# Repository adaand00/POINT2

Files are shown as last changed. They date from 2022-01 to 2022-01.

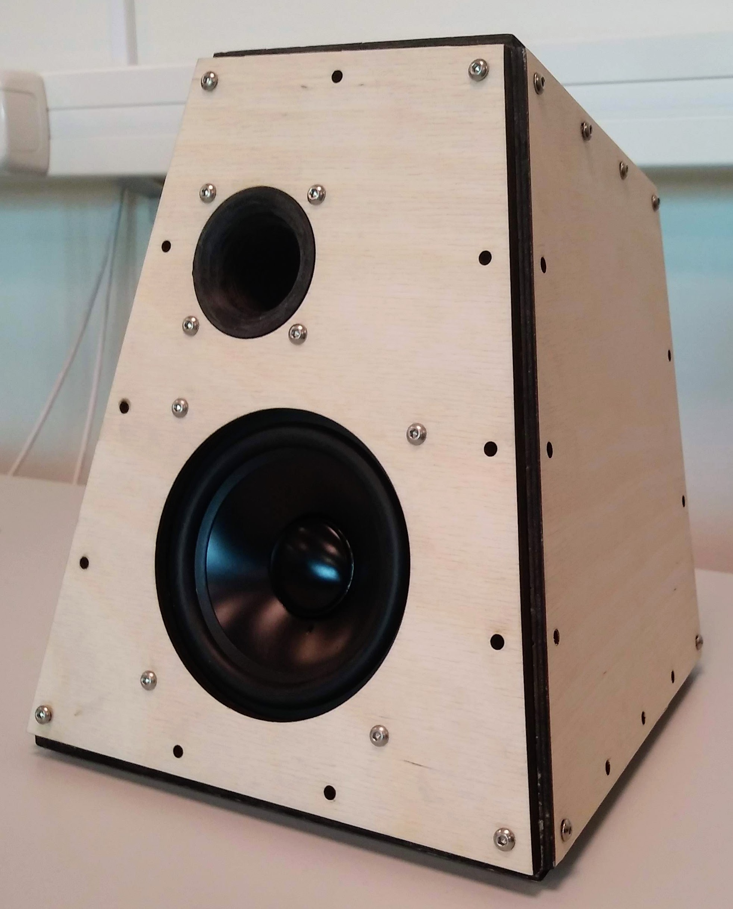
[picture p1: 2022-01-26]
Images/finished.jpg

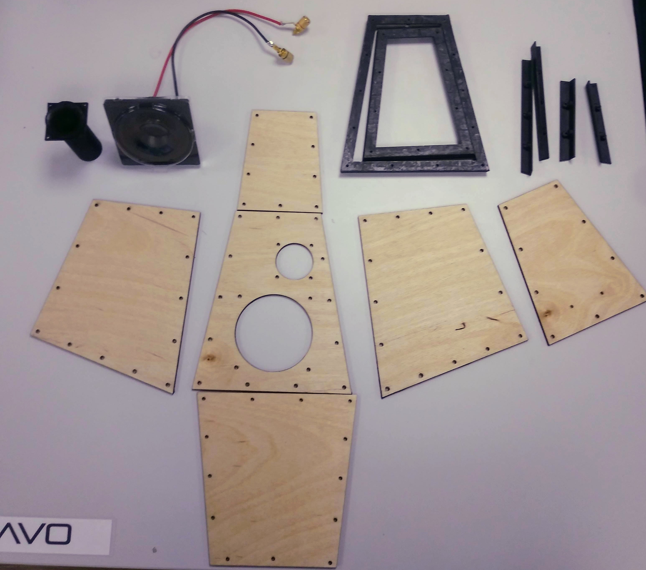
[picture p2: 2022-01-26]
Images/allparts.jpg

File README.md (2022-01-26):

# POINT2 Full-Range Speakers
Designed by Adam Anderson

## Design
The design combines laser cutting and 3D-printing to make a fairly simple speaker that also sounds (surprisingly) good. They use a 3.5" Dayton Audio DMA90 aluminum cone full range driver, which has a fairly linear response all the way through higher frequencies. The ported design also helps the speakers to dig a bit deeper into the bass range, to about 60Hz. The files can easily be changed to accomodate a different driver.

<image src="https://github.com/adaand00/POINT2/raw/main/Images/finished.jpg" width="500px"/>

## Build

The following components are needed to build one speaker:

- ### Dayton Audio DMA90-4 driver
   Can be replaced with another driver, you can probably fit a 4" driver. 
    
- ### 3D printed supports and horn
  The files can be found in `Supports` folder. The parts with `Side` in the name needs to be printed mirrored as well. The speaker will maybe sound better (at least look better) if the horn is sanded smooth. 

- ### Plywood panels
  Dxf files for laser cutting can be found under `Panels`. I used 4mm plywood, remember to use longer screws if you decide to use thicker plywood. 

- ### Sealing tape
  This tape is used to create an airtight seal between all of the panels and to seal the horn. Low-end response is significantly worse if air can escape through somewhere other than the horn. I used 4mm wide tape. 

- ### M3x8 screws
  Probably the defining feature of the build. Too many to count, buy 100 and you will be safe. 

- ### M3x20 screws, M3 nuts
  8 each to mount the speaker and the horn.

- ### Speaker terminals and wires
  I bought banana plug jacks from ebay. You will have to add cutouts in the back panel.
  
## Images 

All parts laid out:

<image src="https://github.com/adaand00/POINT2/raw/main/Images/allparts.jpg" width="500px"/>

Foam applied to edges:

<image src="https://github.com/adaand00/POINT2/raw/main/Images/foam-on.jpg" width="500px"/>

Support structure:

<image src="https://github.com/adaand00/POINT2/raw/main/Images/Render-transparent.png" width="500px"/>

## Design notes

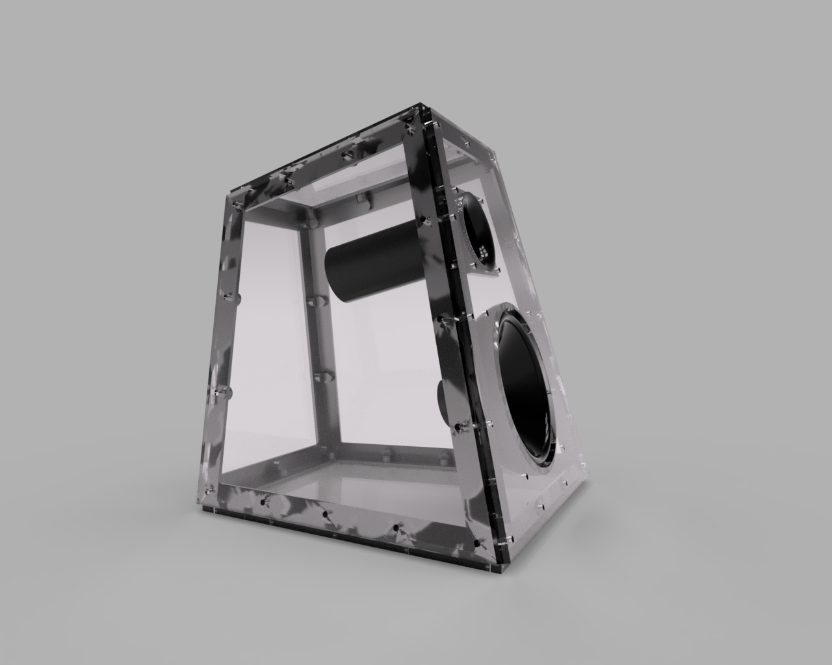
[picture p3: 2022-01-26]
Images/Render-transparent.png

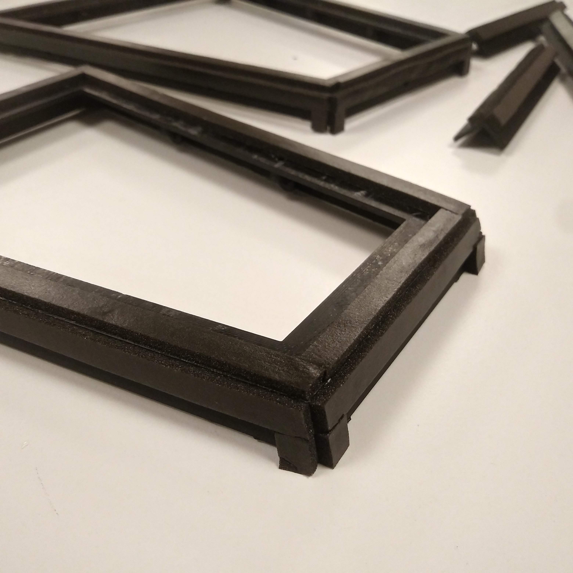
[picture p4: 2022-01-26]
Images/foam-on.jpg

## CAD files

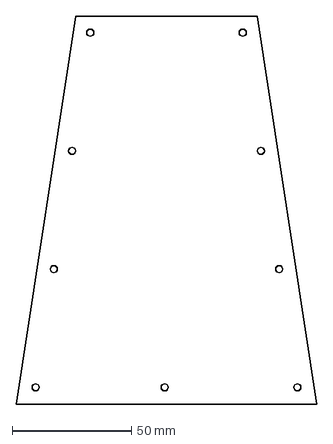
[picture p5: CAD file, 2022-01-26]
Panels/Back.dxf
126.2 x 162.9 mm

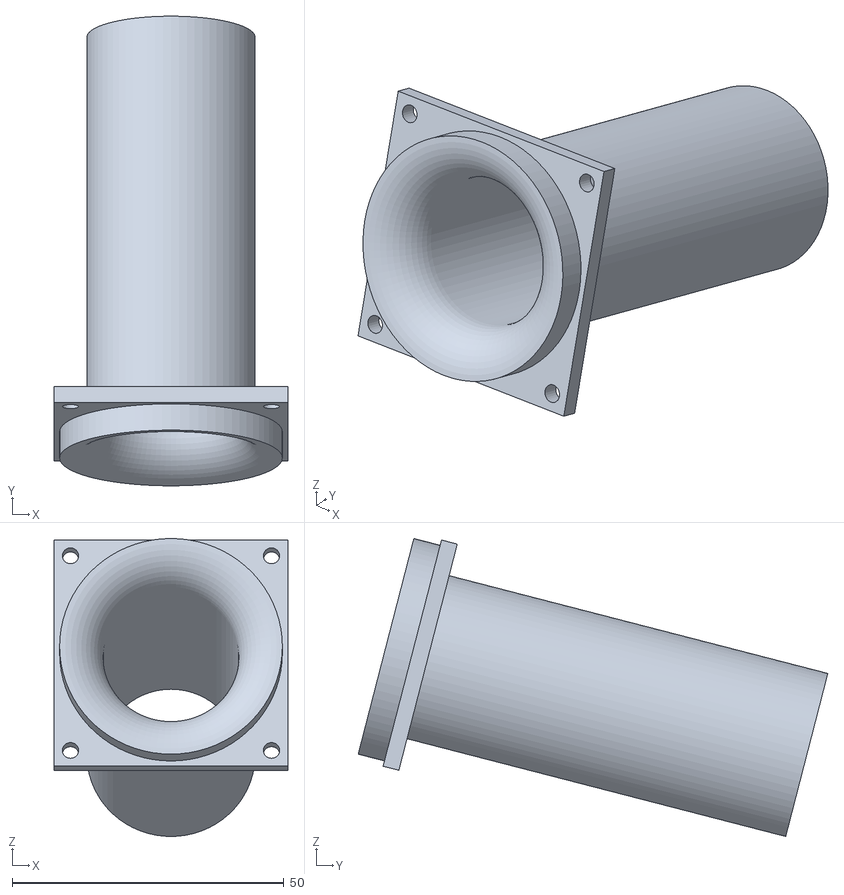
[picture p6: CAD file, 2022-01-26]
Supports/Horn.stl
43.0 x 86.5 x 54.9

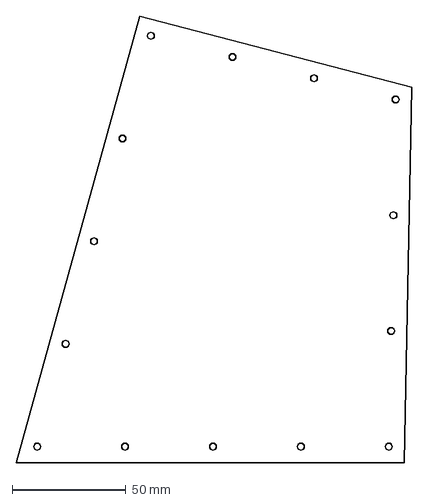
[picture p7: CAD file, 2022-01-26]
Panels/Side.dxf
173.7 x 195.9 mm

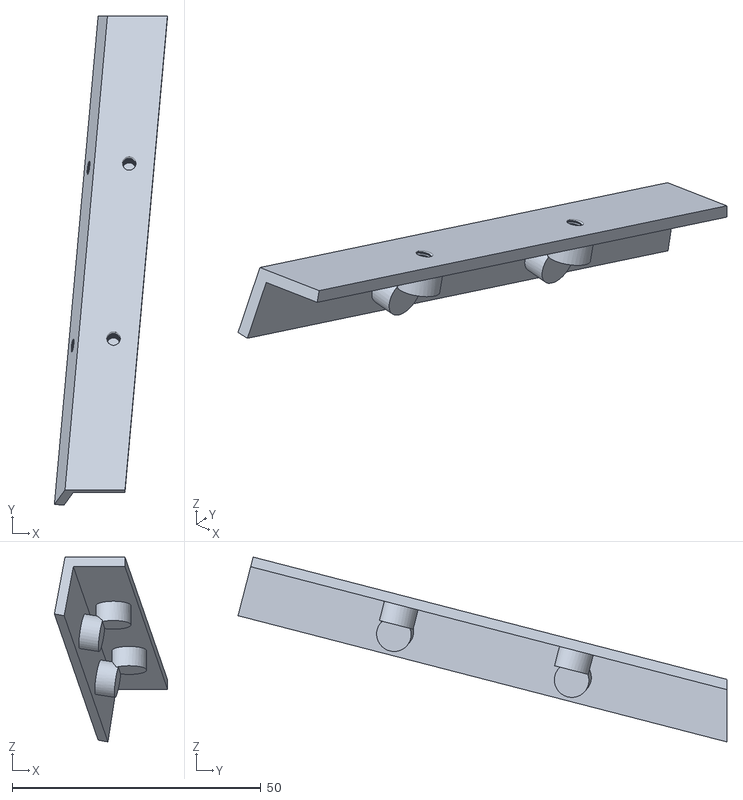
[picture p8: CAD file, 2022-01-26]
Supports/High_side.stl
22.8 x 98.2 x 37.1

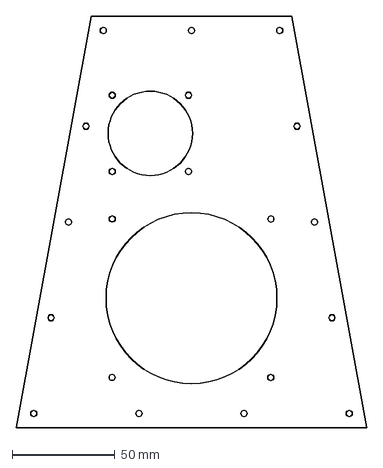
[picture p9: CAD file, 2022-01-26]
Panels/Front.dxf
170.0 x 200.0 mm

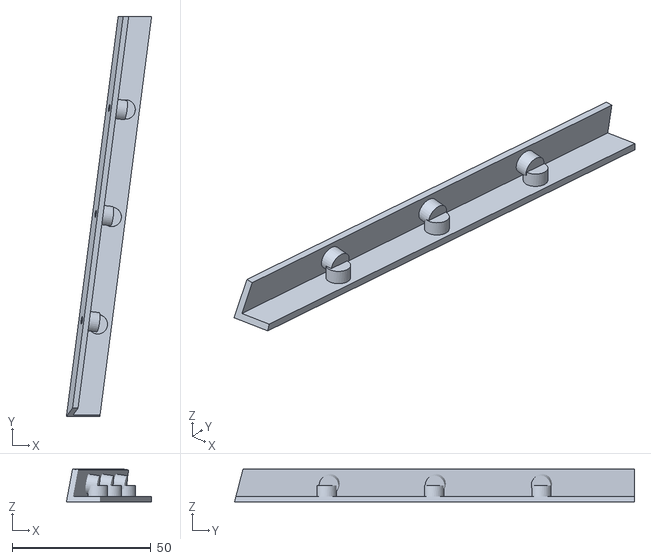
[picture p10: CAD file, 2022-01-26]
Supports/Low_side.stl
30.8 x 144.4 x 11.9

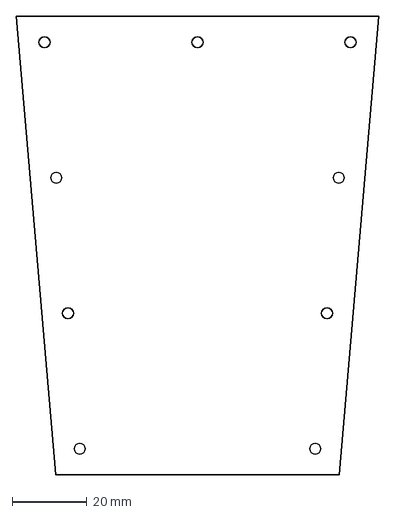
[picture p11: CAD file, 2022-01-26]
Panels/Top.dxf
97.3 x 123.0 mm

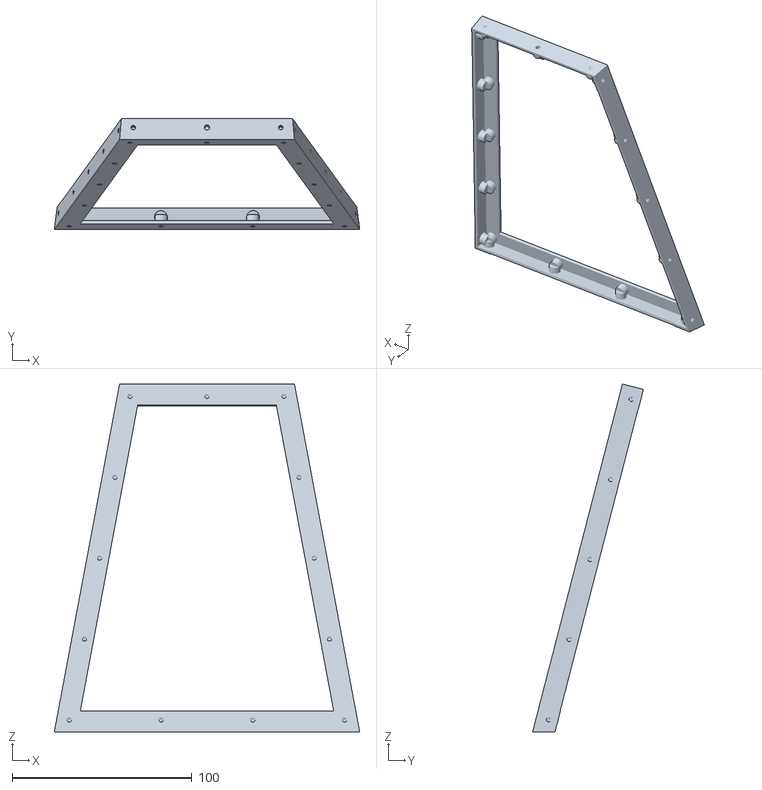
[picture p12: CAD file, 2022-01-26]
Supports/Front.stl
170.0 x 61.7 x 193.6

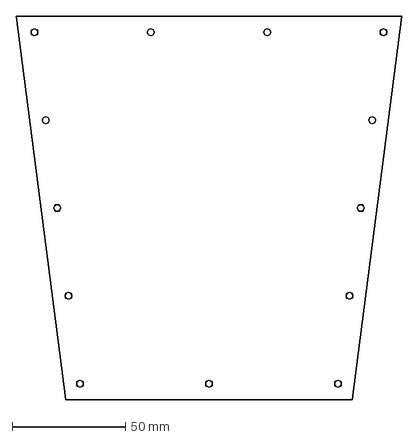
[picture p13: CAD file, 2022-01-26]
Panels/Bottom.dxf
170.0 x 169.1 mm

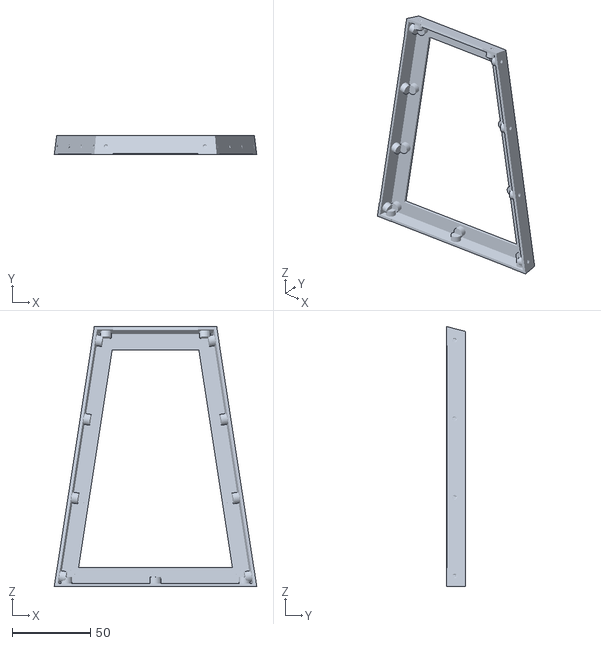
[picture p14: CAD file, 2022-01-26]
Supports/Back.stl
129.4 x 12.2 x 166.0
